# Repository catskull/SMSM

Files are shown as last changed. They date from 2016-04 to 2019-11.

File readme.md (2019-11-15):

# SMSM
## A MIDI interface for the Sega Master System

Originally developed by [little-scale](http://little-scale.blogspot.com/2012/12/how-to-build-sega-master-system-midi.html).

Updated and maintained by [catskull](http://catskull.net).

## Building the ROM
Install wla-dx. On OSX this is easily achieved using by using Homebrew. Simply call `brew install wla-dx` from a command line. If you get a linking error, run ```sudo chown -R `whoami`:admin /usr/local/bin` and then run `brew link wla-dx```. If that completed successfully, run `wla-z80` from the command line and you should see something like this:

```
WLA Z80 Macro Assembler v9.9
Written by Ville Helin in 1998-2008 - In GitHub since 2014: https://github.com/vhelin/wla-dx
$VER: WLA-Z80 9.9 (15.8.2019)

USAGE: wla-z80 [OPTIONS] <ASM FILE>

Options:
-i  Add list file information
-M  Output makefile rules
-q  Quiet
-t  Test compile
-v  Verbose messages
-x  Extra compile time labels & definitions
-I [DIR]  Include directory
-D [DEF]  Declare definition

Output types:
-o [FILE]  Output object file
-l [FILE]  Output library file

EXAMPLE: wla-z80 -v -o main.obj main.asm
```

Congratulations! You're now ready to build the ROM!

cd into the ROM directory. Inside there is SMSM.asm, and build.sh. Enter `./build.sh` from the command line and it will build the ROM for you! You should now see a file called output.sms in this directory. This is the rom! Fire up your favorite emulator and give it a shot!

## ROM improvements

The ROM as developed by little-scale works quite well but is very bare bones. For example, it does not display anything on the screen when booted so there's no way of knowing whether or not your cartridge even works or not!

Here is a list of improvements I've made to the ROM so far:
 - clear the bios screen on boot
 - display a message on boot "System ready!"

Wish list:
 - mGB style console based interface for editing instrument presets (currently that is only supported by MIDI CC commands)
 - Implement the reset button on the console to reset the rom (a sort of MIDI panic)
 - Display a message if the YM2413 FM sound chip is detected

# Hardware

The hardware as developed by little-scale is quite complete. It does most of the heavy lifting, which is why the console ROM is so bare bones.

Here is a list of improvements I have made:
 - Added a status LED on pin 13. It blinks in a pattern and then goes steady on on first boot. Once notes are being sent, it blinks each time a note is received.
 - Added a MIDI panic button. Pressing it will kill all notes on the console.
 - I have designed a small PCB based around the Arduino Pro Mini for easiest use.

Wish list:
 - Currently, the PCB does not work with a Game Gear. It simply does not power on. Powering the unit externally does not work either. It powers on, but will not receive any MIDI data.
 - The PCB interface does not work with my cheapie USB MIDI cable. It will occasionally get midi data, but not reliably and will frequently miss MIDI note off.

# Credits
Sebastian Tomczak (aka little-scale) for the ROM, arduino code, and everything else.

Maxim for a great hello world tutorial.

Everyone at smspower.org

# License

little-scale released this with this note:

"The code etc for this is open and free to use. Please do not commercialise this. It is not for making money. It is for making cool chiptune musics. I encourage you to build one of these. It is easy and shouldn't take long. I encourage you to hack the code and play and have fun with it."

This is not really a valid software license. The ROM is based on Maxim's hello world program which also was not really released with a license.

For the time being, the code is somewhere in between public domain and all rights reserved. All contributions I make will be licensed under GPL v2.

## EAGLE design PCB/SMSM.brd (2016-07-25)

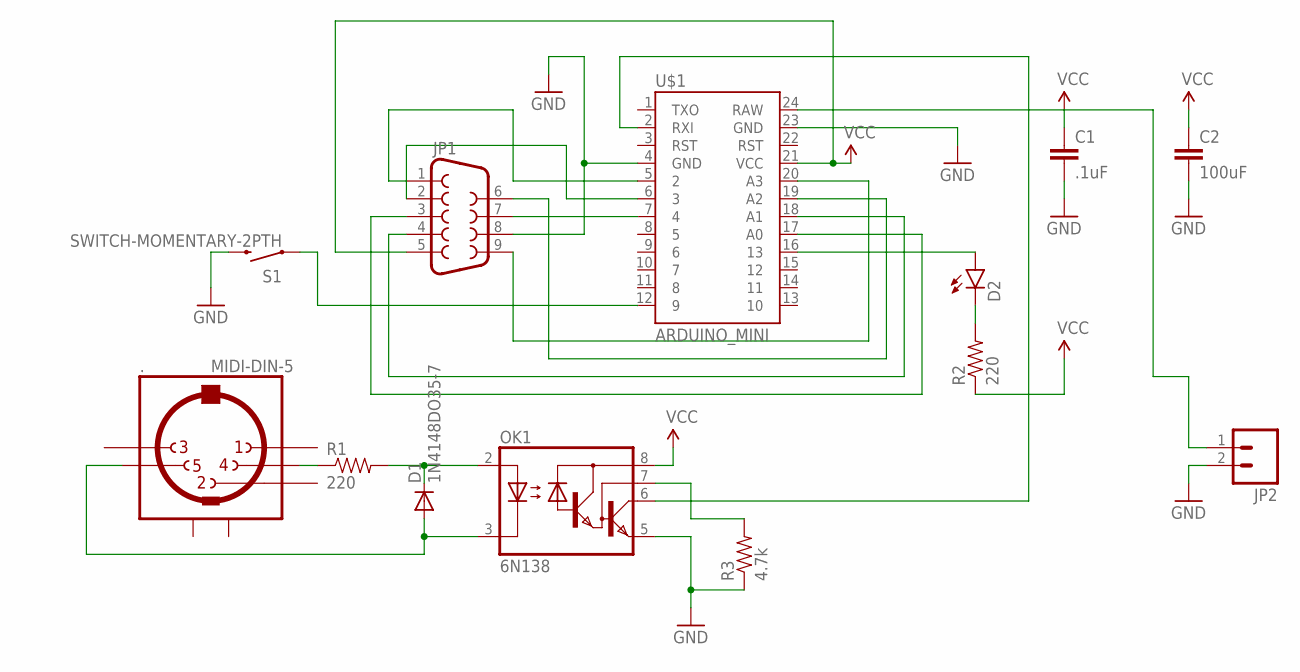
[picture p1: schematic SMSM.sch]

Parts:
.: MIDI-DIN-5
C1: .1uF; CAP-PTH-SMALL-KIT
C2: 100uF; CAP-PTH-SMALL-KIT
D1: 1N4148DO35-7; DO35-7
D2: LED3MM
JP1: DB9FEMALE; DB9
JP2: M02LOCK_LONGPADS; 1X02_LOCK_LONGPADS
OK1: 6N138; DIL08
R1, R2: 220; AXIAL-0.3
R3: 4.7k; AXIAL-0.3
S1: SWITCH-MOMENTARY-2PTH; TACTILE-PTH
U$1: ARDUINO_MINI

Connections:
GND: C1.2, C2.2, JP1.8, JP2.2, OK1.5 (GND), R3.P$1 (1), S1.3 (2), U$1.4 (GND), U$1.23 (GND)
unnamed: JP1.1, U$1.5 (2)
unnamed: JP1.2, U$1.6 (3)
unnamed: JP1.7, U$1.7 (4)
unnamed: D2.A, U$1.16 (13)
unnamed: JP1.3, U$1.17 (A0)
unnamed: JP1.4, U$1.18 (A1)
unnamed: JP1.6, U$1.19 (A2)
unnamed: JP1.9, U$1.20 (A3)
unnamed: ..5, D1.A, OK1.3 (C)
unnamed: D1.C, OK1.2 (A), R1.P$2 (2)
unnamed: D2.K (C), R2.P$2 (2)
unnamed: ..4, R1.P$1 (1)
unnamed: OK1.7 (VB), R3.P$2 (2)
unnamed: OK1.6 (VO), U$1.2 (RXI)
unnamed: S1.1, U$1.12 (9)
unnamed: JP2.1, U$1.24 (RAW)
VCC: C1.1, C2.1, JP1.5, OK1.8 (VCC), R2.P$1 (1), U$1.21 (VCC)

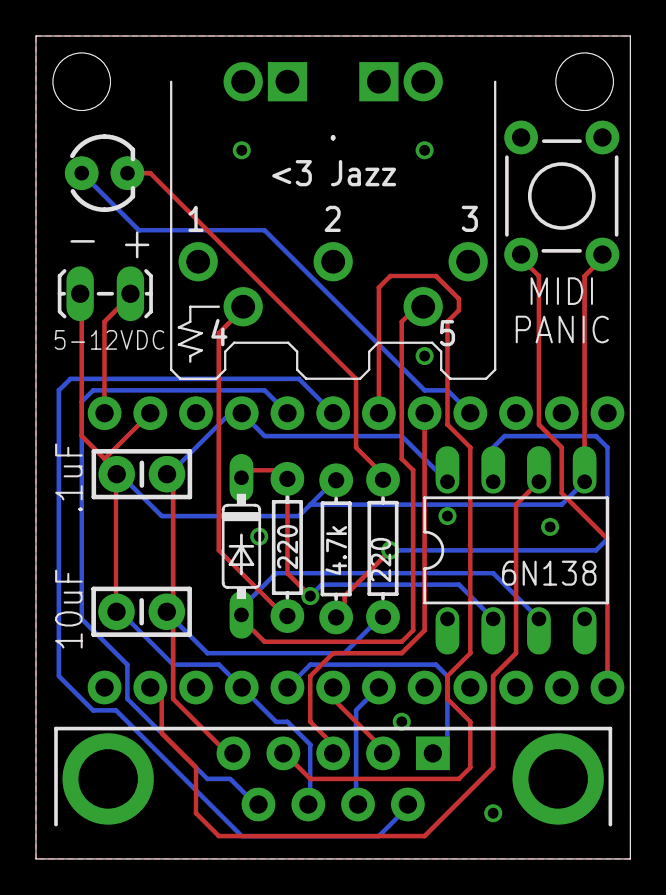
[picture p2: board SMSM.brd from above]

Board: 2 copper layers, 33.0 x 45.7 mm, 13 parts (0 on the bottom side), 18 nets.

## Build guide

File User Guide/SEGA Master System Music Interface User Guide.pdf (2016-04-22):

# SMSM INTERFACE USER GUIDE 1.00

SEGA Master System MIDI Interface User Guide by Sebastian Tomczak

## Contents

## Overview

The SMSM Interface allows one to have complete control over the two sound chips (The SN76489 and the YM2413 (optional in many systems)) within the SEGA Master System console via a MIDI connection.

The interface consists of two parts – a cartridge containing a custom program, and a hardware interface with pre-programmed microcontroller.

## Setup

1. Connect the SMSM hardware interface to the video game console via a 9-pin extension cable (available separately).
2. Connect the MIDI output from your host computer or other MIDI-enabled device to the SMSM hardware interface.
3. Insert the SMSM cartridge into the video game console.
4. Connect the audio output of the video game console to amplification or recording equipment. Video output is not needed. Depending on the console type, you may need to manually add audio outputs or use a DIN-type connection adaptor.
5. MIDI channels 1 to 4 are mapped to SN76489 channels 1 to 4.
6. MIDI channels 5 to 14 are mapped to YM2413 channels 1 to 9 (if YM2413 is available).

## SMSM MIDI Quick Reference

See the following sections for more information.

MIDI channels 1 to 4 are mapped to SN76489 channels 1 to 4.
MIDI channels 5 to 14 are mapped to YM2413 channels 1 to 9 (if YM2413 is available).

SN76489 PSG
Global Control
Parameter | CC | Data Range
Pitch Transposition | 42 | 128
PAL / NTSC Tuning | 83 | 2
Bass mode enabled | 85 | 2

Noise Channel Control (MIDI Ch 4)
C and C#: | High frequency, periodic type
D and D#: | Medium frequency, periodic type
E: | Low frequency, periodic type
F: | High frequency, noise type
F#: | Medium frequency, noise type
G and G#: | Low frequency, noise type
A and A#: | Frequency is determined by channel 3, periodic type
B: | Frequency is determined by channel 3, noise type

Voice Control
Parameter | CC | Data Range
AM mode enabled | 70 | 2
AM speed | 18 | 128
AM depth | 19 | 16
FM mode enabled | 71 | 2
FM speed | 20 | 128
FM depth | 21 | 128
Set channel volume | 11 | 16

Channel 2 Sample Mode

Parameter | CC | Data Range
Sample mode enabled | 78 | 2
Sample playback speed | 86 | 128

YM2413 FM
Global Control
Parameter | CC | Data Range
Set the value of A in Hz | 81 | 128
Equal Tempered Octave Division | 80 | 128
Set pitch bend resolution in semitones | 79 | 10.5
Percussion mode enabled | 78 | 2

Percussion Mode Control (MIDI Ch 14 when Percussion Mode is Enabled) C: Kick Drum
D: Snare Drum
E: Tom
F: Cymbal
G: Hi-hat

Voice Control
Parameter | CC | Data Range
Set instrument | 14 | 16
Custom voice AM (modulator) enabled | 15 | 2
Custom voice AM (carrier) enabled | 16 | 2
Custom voice Vib (m) enabled | 17 | 2
Custom voice Vib (c) enabled | 18 | 2
Custom voice EG type (m) | 19 | 2
Custom voice EG type (c) | 20 | 2
Custom voice KSR on (m) | 21 | 2
Custom voice KSR on (c) | 22 | 2
Custom voice mul (m) | 23 | 16
Custom voice mul (c) | 24 | 16
Custom voice KSL (m) | 25 | 4
Custom voice KSL (c) | 26 | 4

Custom voice TL modulation | 27 | 2
Custom voice rectify wave (m) | 28 | 2
Custom voice rectify wave (c) | 29 | 2
Custom voice FM feedback (m) | 30 | 16
Custom voice attack (m) | 31 | 16
Custom voice decay (m) | 32 | 16
Custom voice sustain (m) | 33 | 16
Custom voice release (m) | 34 | 16
Custom voice attack (c) | 35 | 16
Custom voice decay (c) | 36 | 16
Custom voice sustain (c) | 37 | 16
Custom voice release (c) | 38 | 16
Custom voice sustain mode enabled | 70 | 2

## MIDI Mapping – SN76489

The SN76489 PSG chip contains four channels that are mapped to MIDI channels 1 to 4. Channels 1, 2 and 3 are pulse channels that feature a simple tone generator, which can be used for melodic lines. Channel 4 is a pseudo-random noise generator, which can be used for percussion or effects. Channel 4 can be clocked using channel 3 (in other words – the pitch of channel 3 controls the pitch of channel 4).

The MIDI mapping for the SN76489 is relatively simple and straightforward compared with the YM2413. The SN76489 will respond to the following MIDI CC messages as well as note on, note off and pitch bend events.

SN76489: Global Parameters
PAL / NTSC Tuning | CC83 | Any Channel
2 values over the range of 0 to 127. A CC value of less than 64 sets the interface to the PAL tuning. A value of more than 63 sets the interface to the NTSC tuning. The default setting is PAL.
Pitch Transposition | CC42 | Any Channel
128 values of the range of 0 to 127. Set a global pitch offset of – 64 to + 63 semitones. Default is + or – 0 semitones which is equivalent to a CC value of 64.
Bass Mode Enabled | CC 85 | Any Channel
2 values over the range of 0 to 127. A CC of less than 64 disables Bass Mode for channel 2. A CC value of more than 63 enables Bass Mode for channel 2. When bass mode is enabled, the resources of SN76489 channels 3 and 4 are combined in such a way that MIDI channel 3 is a bass-like voice. This is a simple and musical way to 'clock' SN76489 channel 4 using SN76489 channel 3. See 'SN76489: Noise Channel Control' for more information.

SN76489: Noise Channel Control
The SN76489 has an interesting noise channel. The setting for the noise channel at a given point in time is selected by sending a note on event on MIDI channel 4. Any given pitch (regardless of octave) will produce a different setting for the noise channel, as follows:
C and C#: | High frequency, periodic type
D and D#: | Medium frequency, periodic type
E: | Low frequency, periodic type
F: | High frequency, noise type
F#: | Medium frequency, noise type

G and G#: | Low frequency, noise type
A and A#: | Frequency is determined by channel 9, periodic type
B: | Frequency is determined by channel 9, noise type

One way of handling the control of channel 4 using channel 3 is by sending note on events on channel 3 with a velocity below 7 (which will set the frequency of the noise channel) at the same time as sending note on events on channel 4 with a pitch of A, A# or B and with a high velocity (which will set the tone type – either noise or periodic – of the noise noise channel).

'Bass Mode' simplified way of controlling the frequency of the noise channel using channel 3. See 'Bass Mode Enabled' for more information.

SN76489: Voice Control Control
AM Mode Enabled | CC 70 | Channels 1, 2 and 3
2 values over the range of 0 to 127. A CC of less than 64 disables AM Mode a given channel. A CC value of more than 63 enables AM mode for a given channel. AM (amplitude modulation) allows for a range of effects, from timbral changes to tremolo and distortion.
AM Speed | CC18 | Channels 1, 2 and 3
128 values over the range of 0 to 127. The lower the CC value, the fast the speed of the amplitude modulation. Whether or not or not other MIDI channels are very active or have AM enabled will influence the actual frequency of the amplitude modulation for a given channel.
AM Depth | CC19 | Channels 1, 2 and 3
16 values over the range of 0 to 127. The lower the CC value, the less of an effect the amplitude modulation will have on a given voice.
FM (Vibrato) Mode Enabled | CC 70 | Channels 1, 2 and 3
2 values over the range of 0 to 127. A CC of less than 64 disables FM Mode a given channel. A CC value of more than 63 enables FM mode for a given channel. AM (frequency modulation) allows for a range of effects, from timbral changes to vibrato and distortion.
FM (Vibrato) Speed | CC18 | Channels 1, 2 and 3
128 values over the range of 0 to 127. The lower the CC value, the fast the speed of the amplitude modulation. Whether or not or not other MIDI channels are very active or have FM enabled will influence the actual frequency of the frequency modulation for a given channel.
FM (Vibrato) Depth | CC19 | Channels 1, 2 and 3

16 values over the range of 0 to 127. The lower the CC value, the less of an effect the frequency modulation will have on a given voice.
Set Channel Volume | CC11 | All Channels
16 values over the range of 0 to 127. Set the volume of a given channel. Can be used to draw envelopes.

SN76489: Channel 2 Sample Mode
Sample Mode Enabled | CC78 | Channel 2
2 values over the range of 0 to 127. A CC of less than 64 disables the sample mode. A CC value of more than 63 enables the sample mode. The sample mode can only be enabled for SN76489 channel 2. Note that due to the difference in volume for samples compared to the pulse waves, when sample mode is enabled, the volume of all notes is set to 1/3.
Sample Playback Speed | CC86 | Channel 2
128 values over the range of 0 to 127. The lower the CC value, the faster the sample playback speed is.

## MIDI Mapping – YM2413

The YM2413 is an FM chip and can play either 9 pitched channels or 6 pitches channels and 5 percussive sounds at once. The FM synthesis is relatively simple, and consists of a single modulator / single carrier-type model. The sound chip contains 15 preset instruments.

MIDI channels 5 to 13 are mapped to YM2413 pitched channels 1 to 9.
MIDI channel 14 is mapped to YM2413 percussion mode.

YM2413: Global Control
Set the value of A in Hz | CC81 | Any Channel
128 values over the range of 0 to 127. The value of the concert A and all other pitches relative to concert A is set by the following equation: Concert A = 381 + CC value (in Hz). For example, a CC value of 63 will give that Concert A = 381 + 63 = 440 Hz. This CC gives the user control over tuning; there is no need to change this CC from the default value in order to have standard tuning.
Equal Tempered Octave Division | CC80 | Any Channel
128 values over the range of 0 to 127. Sets the global equal-tempered division of the octave. The tuning of the interface is equal to (CC + 1) TET. The default is an equal division of the octave into twelve parts (the Western music scale), which is equivalent to a CC value of 11. Values above CC value = 17 may yield unexpected results. This CC gives the user control over tuning; there is no need to change this CC from the default value in order to have standard tuning.
Set Pitch Bend Resolution in Semitones | CC79 | Any Channel
10.5 values over the range of 0 to 127. Sets the global pitch-bend value in semitones, from +/- 0 semitones to +/- 12 semitones.
Percussion Mode Enabled | CC78 | Any Channel
2 values over the range of 0 to 127. A CC of less than 64 disables percussion mode. A CC value of more than 63 enables percussion mode. Percussion mode uses the resources of pitched channel 7, 8 and 9 in order to create 5 percussive sounds: kick drum, snare drum, tom, cymbal and hi-hat.

When in percussion mode:
- Only YM2413 pitched channels 1 to 6 are available for direct use
- As a result, only MIDI channels 5 to 10 will respond properly to MIDI note on / off events.
- MIDI channel 14 allows control over the YM2413 percussion mode

YM2413: Percussion Mode Control
MIDI Channel 14 control the percussive sounds. A note / off event for the following pitches (regardless of octave) will trigger the following percussive sounds when Percussion Mode is enabled (see 'Percussion Mode Enabled').

C: Kick Drum
D: Snare Drum
E: Tom
F: Cymbal
G: Hi-hat

Yamaha recommends a predetermined frequency setting for each of the operators that constitute the percussion when in drum mode, but these preset frequencies can sound quite bland and boring. By sending a CC value of more than 64, these preset-values are recalled automatically.

However, because these sounds are made using the operators that normally make up YM2413 pitched channels 7, 8 and 9, it is still possible to tune the operators to a certain degree by simply sending MIDI pitches to MIDI channels 11, 12 and 13. This then essentially 'tunes' the drum sounds, giving a wider variety of sounds, and even the possibility of playing melodies using the percussive sounds.

YM2413: Voice Control
Set Instrument | CC14 | Any Channel
16 values over the range of 0 to 127. Sets a given channel to an instrument preset. The instrument presets are as follows:
1. (Custom Voice)
2. Violin
3. Guitar
4. Piano
5. Flute
6. Clarinet
7. Oboe
8. Trumpet
9. Organ
10. Horn
11. Synthesizer
12. Harpsichord
13. Vibraphone

14. Synthesizer Bass
15. Acoustic Bass
16. Electric Bass

Note that the custom voice settings are identical for all channels – the custom voice is a global instrument with global parameters. See below for these parameters and how they are controlled.

Custom Voice AM (Modulator) Enabled | CC15 | Any Channel
2 values over the range of 0 to 127. A CC of less than 64 disables AM mode for the custom voice modulator. A CC value of more than 63 enables AM mode for the custom voice modulator.
Custom Voice AM (Carrier) Enabled | CC16 | Any Channel
2 values over the range of 0 to 127. A CC of less than 64 disables AM mode for the custom voice carrier. A CC value of more than 63 enables AM mode for the custom voice carrier.
Custom Voice Vibrato (Modulator) Enabled | CC17 | Any Channel
2 values over the range of 0 to 127. A CC of less than 64 disables vibrato mode for the custom voice carrier. A CC value of more than 63 enables vibrato mode for the custom voice carrier.
Custom Voice Vibrato (Carrier) Enabled | CC18 | Any Channel
2 values over the range of 0 to 127. A CC of less than 64 disables vibrato mode for the custom voice carrier. A CC value of more than 63 enables vibrato mode for the custom voice carrier.
Custom Voice EG Type (Modulator) | CC19 | Any Channel
2 values over the range of 0 to 127. A CC of less than 64 sets the envelope generator of the custom voice modulator to the sustained type. A CC of more than 63 sets the envelope generator of the custom voice modulator to the percussive type.
Custom Voice EG Type (Carrier) | CC20 | Any Channel
2 values over the range of 0 to 127. A CC of less than 64 sets the envelope generator of the custom voice carrier to the sustained type. A CC of more than 63 sets the envelope generator of the custom voice carrier to the percussive type.
Custom Voice KSR (Modulator) Enabled | CC21 | Any Channel
2 values over the range of 0 to 127. A CC of less than 64 disables key scale rate mode for the custom voice modulator. A CC value of more than 63 enables key scale rate mode for the custom voice modulator. Key scale rate can give instruments a more natural sound – as the pitch of the instrument rises, the amplitude envelope becomes faster.

Custom Voice KSR (Carrier) Enabled | CC22 | Any Channel
2 values over the range of 0 to 127. A CC of less than 64 disables key scale rate mode for the custom voice carrier. A CC value of more than 63 enables key scale rate mode for the custom voice carrier. Key scale rate can give instruments a more natural sound – as the pitch of the instrument rises, the amplitude envelope becomes faster.
Custom Voice Mul (Modulator) | CC23 | Any Channel
16 values over the range of 0 to 127. Sets the frequency multiplier of the custom voice modulator, from a ratio of ½ to a ratio of 15.
Custom Voice Mul (Carrier) | CC24 | Any Channel
16 values over the range of 0 to 127. Sets the frequency multiplier of the custom voice carrier, from a ratio of ½ to a ratio of 15.
Custom Voice KSL (Modulator) | CC25 | Any Channel
4 values over the range of 0 to 127. A CC of less than 64 disables key scale level mode for the custom voice modulator. A CC value of more than 63 enables key scale rate mode for the custom voice modulator. Key scale level can give instruments a more natural sound – as the pitch of the instrument rises, the output volume level drops.
Custom Voice KSL (Modulator) | CC26 | Any Channel
4 values over the range of 0 to 127. A CC of less than 64 disables key scale level mode for the custom voice carrier. A CC value of more than 63 enables key scale rate mode for the custom voice modulator. Key scale level can give instruments a more natural sound – as the pitch of the instrument rises, the output volume level drops.
Custom Voice TL Modulation | CC27 | Any Channel
64 values over the range of 0 to 127. The TL modulation controls the amount that the custom voice modulator modulates the custom voice carrier by. A wide variety of tones can be achieved by changing the TL modulation amount in conjunction with other custom voice parameters.
Custom Voice Rectify (Modulator) Enabled | CC28 | Any Channel
2 values over the range of 0 to 127. A CC of less than 64 disables rectify waveform mode for the custom voice modulator. A CC value of more than 63 enables rectify waveform mode for the custom voice modulator.
Custom Voice Rectify (Carrier) Enabled | CC29 | Any Channel
2 values over the range of 0 to 127. A CC of less than 64 disables rectify waveform mode for the custom voice modulator. A CC value of more than 63 enables rectify waveform mode for the custom voice modulator.

FM Feedback Amount | CC30 | Any Channel
8 values over the range of 0 to 127. Sets the amount of FM feedback. Distortion and timbre can be explored via this parameter.

One of the most important aspects of controlling the two operators of the YM2413 custom voice is through the amplitude (volume) envelope generator. Below is a basic representation of the envelope and its parameters. The YM2413 custom voice has one of two envelope types – either a sustained envelope or a percussive envelope. See 'Custom Voice EG Type (Modulator)'.

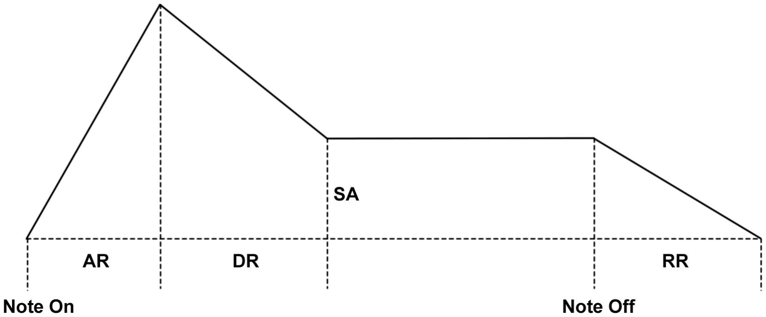
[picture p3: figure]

(envelope for a sustained envelope – see 'Custom Voice EG Type (Modulator)')

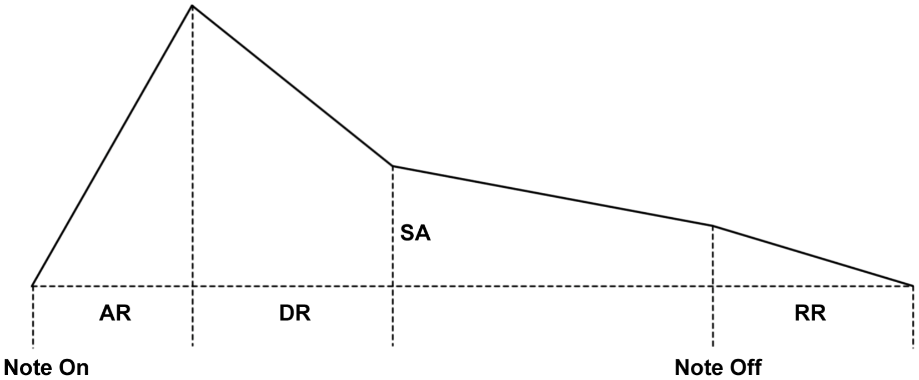
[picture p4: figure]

(envelope for a percussive envelope – see 'Custom Voice EG Type (Modulator)')

In relation to the above diagram, the horizontal axis represents time while the vertical axis represents amplitude. The Note On and Note Off events refer to their MIDI counter parts in the context of this MIDI interface.

AR = Attack Rate

DR = Decay Rate
SA = Sustain Amount
RR = Release Rate
Custom Voice Attack (Modulator) | CC31 | Any Channel
16 values over the range of 0 to 127. Sets the attack rate of the custom voice modulator.
Custom Voice Decay (Modulator) | CC32 | Any Channel
16 values over the range of 0 to 127. Sets the decay rate of the custom voice modulator.
Custom Voice Sustain (Modulator) | CC33 | Any Channel
16 values over the range of 0 to 127. Sets the attack rate of the custom voice modulator.
Custom Voice Release (Modulator) | CC34 | Any Channel
16 values over the range of 0 to 127. Sets the attack rate of the custom voice modulator.
Custom Voice Attack (Carrier) | CC35 | Any Channel
16 values over the range of 0 to 127. Sets the attack rate of the custom voice carrier.
Custom Voice Decay (Carrier) | CC36 | Any Channel
16 values over the range of 0 to 127. Sets the decay rate of the custom voice carrier.
Custom Voice Sustain (Carrier) | CC37 | Any Channel
16 values over the range of 0 to 127. Sets the attack rate of the custom voice carrier.
Custom Voice Release (Carrier) | CC38 | Any Channel
16 values over the range of 0 to 127. Sets the attack rate of the custom voice carrier.
Custom Voice Sustain Mode Enabled | CC70 | Any Channel
2 values over the range of 0 to 127. A CC of less than 64 disables sustain mode for the custom voice. A CC value of more than 63 enables sustain mode for the custom voice.

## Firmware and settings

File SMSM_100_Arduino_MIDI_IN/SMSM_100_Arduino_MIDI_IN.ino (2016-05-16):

// SEGA Master System MIDI Interface for Arduino MIDI In
// SMSM Firmware v1.0.1
// by little-scale
// Released 3 December 2012
// updated by catskull
// on 16 May 2016




/* Arduino Hardware

SMS Player 2 Port Pin 1 <-- Arduino Pin 2
SMS Player 2 Port Pin 2 <-- Arduino Pin 3
SMS Player 2 Port Pin 3 <-- Arduino Analog Input Pin 0
SMS Player 2 Port Pin 4 <-- Arduino Analog Input Pin 1
SMS Player 2 Port Pin 5 No Connection
SMS Player 2 Port Pin 6 <-- Arduino Analog Input Pin 2
SMS Player 2 Port Pin 7 <-- Arduino Pin 4
SMS Player 2 Port Pin 8 <-> Arduino Ground
SMS Player 2 Port Pin 9 <-- Arduino Analog Input Pin 3

*/




// Arduino Software


#include <avr/pgmspace.h>
#include <math.h>

#define MODE_NTSC 83
#define MODE_PAL 0

#define MIDI_PANIC_PRESSED 0
#define MIDI_PANIC_BUTTON 9

#define STATUS_LED 13

// FM VALUES

byte prev_address;
byte out_data;
byte shadow[56];
byte fm_pitches[9];

byte drum;
byte drum_key;
double fm_pitch;
int fm_bend_res = 12;
byte fm_pitch1;
byte fm_pitch2;
byte fm_block;
byte fm_offset;
int note_A = 444;
byte fm_octave_div = 12;
double fm_bend[9];





// SAMPLES BEGINS HERE
int SPB_flag = 0;
int SPB_sound = 0;
int SPB_counter = 0;
int SPB_speed = 0;
int SPB_tick = 1;
int sample_on = 0; // turn sample mode on
byte SPB_volume;

int SPB_max = 400;

int sample_length_list[] = {
  900, // kick 1
  600, // snare 1
  400, // hat c1
  900, // hat o1
  1300, // tom1
  4000, // ride1
  400,
  300,
  1000,
  2000,
  2000,
  1500,
  720,
  1500,
  1500,
  900,
  500,
  1500,
  1000,
  1000
};






const char kick1[] PROGMEM = {
119, 120, 135, 118, 102, 84, 67, 50, 16, 17, 33, 38, 120, 171, 188, 240, 255, 255, 255, 255, 255, 255, 238, 237, 203, 187, 170, 153, 137, 136, 119, 119, 118, 101, 84, 67, 50, 33, 17, 17, 17, 17, 17, 34, 34, 34, 35, 51, 51, 51, 68, 68, 85, 85, 102, 103, 119, 119, 136, 135, 120, 136, 136, 136, 153, 153, 154, 170, 187, 187, 187, 188, 203, 187, 187, 187, 187, 187, 170, 170, 170, 170, 170, 170, 170, 170, 170, 170, 170, 153, 153, 136, 136, 135, 119, 119, 102, 102, 102, 102, 102, 85, 85, 85, 85, 85, 85, 85, 85, 86, 102, 102, 101, 85, 85, 85, 86, 102, 102, 103, 119, 119, 136, 136, 136, 137, 153, 153, 153, 153, 153, 153, 153, 153, 153, 154, 170, 170, 170, 170, 153, 153, 153, 152, 136, 136, 136, 135, 119, 119, 119, 119, 120, 136, 136, 136, 135, 119, 119, 119, 119, 119, 119, 119, 119, 119, 119, 119, 119, 119, 119, 119, 119, 119, 119, 119, 118, 102, 119, 119, 119, 119, 119, 119, 119, 119, 119, 119, 119, 119, 136, 136, 136, 136, 136, 136, 136, 136, 136, 136, 136, 136, 136, 136, 136, 136, 136, 136, 136, 136, 136, 136, 136, 136, 136, 136, 136, 136, 136, 136, 136, 136, 136, 136, 136, 136, 136, 136, 136, 136, 136, 136, 136, 136, 136, 136, 119, 119, 119, 119, 119, 119, 119, 119, 119, 119, 119, 119, 119, 119, 119, 119, 119, 119, 119, 119, 119, 119, 119, 119, 119, 136, 136, 136, 136, 136, 136, 136, 136, 119, 119, 119, 119, 119, 119, 119, 119, 119, 119, 136, 136, 136, 136, 136, 136, 136, 136, 136, 136, 136, 136, 136, 136, 136, 136, 136, 136, 136, 136, 136, 136, 136, 136, 135, 119, 119, 119, 119, 119, 119, 119, 119, 119, 119, 119, 119, 119, 119, 119, 119, 119, 119, 119, 119, 119, 119, 119, 119, 119, 119, 119, 119, 119, 119, 119, 119, 119, 119, 119, 119, 119, 119, 119, 119, 119, 119, 119, 119, 136, 136, 136, 136, 136, 136, 136, 136, 136, 136, 136, 136, 136, 136, 136, 136, 136, 136, 136, 136, 136, 136, 136, 136, 136, 136, 135, 119, 119, 119, 119, 119, 119, 119, 119, 119, 119, 136, 136, 136, 136, 136, 136, 136, 136, 119, 119, 119, 119, 119, 119, 119, 119, 119, 119, 119, 119, 119, 119, 119, 119, 119, 119, 119, 119, 119, 119, 119, 119, 119, 119, 136, 136, 136, 136, 136, 136, 136, 136, 136, 136, 136, 136, 136, 136, 136, 136, 136, 136, 136, 136, 136, 136, 136, 136, 136, 136, 136, 136, 136, 136, 136
};

const char snare1[] PROGMEM = {
136, 119, 119, 123, 256, 255, 155, 0, 1, 57, 206, 239, 255, 222, 219, 135, 32, 0, 0, 0, 19, 189, 191, 255, 255, 238, 182, 0, 0, 0, 3, 57, 207, 236, 255, 254, 220, 16, 0, 4, 52, 101, 136, 137, 204, 205, 254, 154, 115, 18, 18, 20, 84, 185, 189, 204, 202, 155, 153, 103, 84, 101, 70, 117, 103, 168, 138, 136, 153, 169, 170, 134, 104, 117, 86, 119, 100, 104, 137, 152, 171, 185, 152, 153, 117, 103, 70, 120, 103, 103, 118, 154, 139, 186, 135, 153, 118, 87, 82, 69, 104, 137, 170, 136, 153, 137, 134, 102, 118, 103, 85, 120, 102, 120, 122, 136, 137, 136, 152, 134, 102, 102, 103, 118, 119, 104, 136, 136, 136, 120, 152, 120, 119, 103, 104, 119, 136, 134, 151, 134, 136, 137, 136, 136, 134, 119, 100, 102, 102, 120, 137, 152, 153, 152, 136, 136, 117, 118, 118, 119, 120, 120, 120, 152, 152, 136, 118, 119, 119, 136, 119, 135, 103, 120, 135, 119, 136, 136, 135, 135, 118, 120, 119, 136, 136, 120, 136, 120, 120, 118, 136, 119, 120, 120, 118, 119, 120, 136, 120, 136, 136, 119, 136, 119, 119, 119, 119, 136, 136, 120, 136, 136, 120, 135, 103, 119, 119, 118, 136, 135, 152, 136, 136, 119, 135, 119, 119, 119, 135, 120, 136, 135, 135, 119, 135, 119, 135, 136, 135, 120, 135, 136, 135, 119, 119, 120, 136, 135, 120, 136, 120, 135, 119, 119, 120, 119, 119, 120, 120, 136, 119, 119, 119, 119, 119, 119, 135, 136, 136, 135, 119, 119, 135, 119, 135, 135, 120, 136, 120, 136, 135, 135, 135, 119, 119, 119, 119, 119, 120, 120, 136, 136, 136, 119, 119, 119, 135, 119, 119, 120
};

const char hatc1[] PROGMEM = {
136, 136, 133, 112, 58, 34, 104, 75, 119, 25, 114, 72, 103, 54, 184, 150, 86, 102, 135, 149, 73, 185, 101, 134, 69, 104, 118, 136, 134, 185, 119, 104, 151, 104, 197, 214, 121, 119, 134, 134, 121, 152, 118, 118, 135, 169, 119, 135, 120, 136, 105, 136, 152, 151, 104, 104, 134, 120, 137, 103, 103, 103, 118, 120, 120, 136, 137, 120, 120, 104, 135, 119, 151, 136, 151, 136, 119, 119, 120, 120, 136, 136, 120, 136, 119, 136, 136, 135, 136, 120, 120, 135, 135, 135, 135, 120, 135, 120, 136, 135, 135, 120, 135, 136, 135, 135, 119, 136, 136, 120, 120, 135, 119, 119, 120, 120, 136, 120, 119, 135, 119, 119, 135, 135, 119, 135, 136, 119, 119, 135, 119, 135, 135, 120, 119, 135, 120, 120, 119, 136, 119, 119, 120, 119, 135, 135, 120, 119, 119, 119, 119, 135, 119, 119, 119, 119, 120, 119, 119, 119, 135, 136, 119, 119, 119, 119, 119, 119, 119, 119, 119, 135, 119, 119, 135, 120, 119, 135, 120, 135, 119, 119, 119, 119, 136, 135, 119, 136, 120, 119, 136, 120, 135, 135, 120, 119, 135, 136, 119, 119
};

const char hato1[] PROGMEM = {
120, 136, 136, 117, 111, 169, 85, 90, 119, 199, 167, 166, 55, 74, 53, 123, 105, 92, 73, 182, 80, 166, 107, 135, 86, 140, 135, 103, 119, 171, 118, 138, 165, 106, 152, 89, 136, 117, 237, 120, 119, 136, 153, 101, 134, 204, 187, 116, 135, 137, 214, 102, 70, 118, 153, 136, 102, 116, 153, 119, 87, 133, 137, 118, 91, 104, 155, 149, 105, 139, 152, 86, 104, 120, 169, 166, 26, 121, 138, 101, 134, 184, 120, 182, 139, 108, 104, 119, 101, 118, 136, 105, 120, 138, 119, 133, 168, 104, 153, 103, 86, 170, 135, 135, 119, 120, 120, 119, 119, 103, 117, 136, 105, 120, 87, 135, 135, 137, 151, 118, 105, 136, 119, 119, 134, 120, 185, 152, 135, 136, 138, 136, 136, 151, 135, 136, 151, 152, 136, 105, 87, 118, 152, 103, 147, 165, 119, 118, 152, 121, 168, 136, 135, 120, 118, 87, 105, 25, 120, 152, 119, 151, 150, 154, 70, 86, 120, 120, 102, 134, 103, 119, 121, 119, 120, 119, 135, 135, 119, 120, 136, 135, 152, 120, 169, 170, 152, 134, 136, 121, 119, 151, 135, 152, 120, 135, 121, 87, 135, 167, 136, 134, 136, 103, 122, 134, 136, 135, 120, 153, 152, 120, 120, 120, 119, 119, 183, 137, 136, 121, 135, 152, 151, 103, 135, 120, 135, 120, 135, 119, 119, 135, 119, 136, 136, 119, 119, 120, 135, 136, 120, 118, 120, 150, 152, 119, 120, 153, 121, 119, 119, 120, 135, 167, 87, 135, 136, 136, 86, 104, 135, 152, 120, 120, 136, 152, 119, 136, 135, 120, 121, 118, 104, 137, 135, 119, 120, 118, 119, 119, 136, 151, 120, 135, 152, 135, 120, 120, 120, 136, 135, 135, 136, 136, 135, 118, 136, 120, 136, 119, 120, 135, 121, 135, 119, 119, 136, 120, 119, 135, 103, 120, 120, 119, 135, 120, 135, 119, 119, 120, 119, 134, 135, 135, 119, 119, 119, 120, 104, 119, 135, 136, 119, 136, 151, 104, 120, 120, 136, 136, 119, 119, 120, 136, 136, 135, 119, 135, 119, 135, 136, 119, 119, 135, 120, 120, 136, 135, 135, 119, 136, 119, 135, 119, 136, 119, 119, 119, 119, 119, 119, 135, 119, 135, 134, 120, 119, 120, 119, 119, 136, 134, 136, 120, 119, 136, 134, 135, 119, 120, 136, 135, 135, 120, 135, 136, 119, 136, 135, 120, 120, 135, 135, 136, 135, 120, 135, 135, 136, 135, 136, 119, 120, 136, 136, 135, 119, 119, 136, 135, 119, 119, 120, 120, 135, 120, 119, 136, 119, 119, 119, 120, 135, 120, 119, 119, 136, 120, 119, 119, 120, 119, 119, 136, 135, 120, 119, 119, 136, 120
};

const char tom1[] PROGMEM = {
136, 136, 136, 137, 154, 223, 200, 109, 0, 36, 49, 5, 108, 240, 253, 235, 134, 116, 83, 35, 99, 32, 3, 57, 171, 137, 254, 255, 253, 151, 132, 118, 68, 17, 20, 102, 136, 137, 174, 255, 254, 185, 137, 135, 132, 33, 34, 85, 87, 104, 137, 187, 205, 222, 221, 185, 150, 85, 50, 35, 52, 70, 102, 136, 155, 220, 204, 188, 186, 136, 134, 101, 68, 66, 36, 84, 103, 136, 154, 187, 204, 204, 185, 152, 118, 86, 85, 84, 84, 68, 86, 103, 137, 170, 189, 220, 187, 170, 152, 118, 84, 68, 68, 68, 84, 86, 103, 137, 187, 204, 220, 186, 169, 152, 118, 85, 50, 51, 69, 85, 102, 120, 154, 171, 204, 187, 187, 169, 135, 101, 68, 67, 68, 68, 86, 119, 120, 138, 171, 188, 203, 186, 168, 135, 102, 85, 68, 68, 68, 86, 103, 136, 154, 187, 187, 170, 170, 152, 136, 118, 102, 85, 68, 68, 86, 103, 136, 137, 170, 170, 170, 170, 153, 136, 118, 101, 85, 85, 86, 102, 119, 119, 120, 153, 153, 169, 153, 154, 152, 136, 118, 102, 102, 102, 102, 102, 103, 119, 120, 136, 136, 137, 153, 153, 153, 153, 152, 135, 102, 101, 85, 86, 102, 103, 119, 120, 153, 154, 170, 170, 169, 153, 136, 119, 118, 85, 85, 69, 86, 102, 120, 137, 170, 170, 169, 153, 153, 152, 136, 119, 118, 101, 85, 85, 86, 119, 120, 137, 153, 153, 153, 153, 153, 152, 136, 119, 119, 102, 102, 101, 102, 102, 103, 119, 137, 153, 154, 169, 153, 153, 136, 135, 118, 102, 102, 102, 102, 101, 103, 120, 136, 153, 153, 153, 153, 152, 136, 136, 135, 119, 119, 118, 102, 102, 102, 103, 120, 136, 136, 136, 137, 153, 153, 153, 136, 136, 136, 119, 118, 101, 101, 85, 102, 103, 120, 153, 170, 169, 153, 136, 136, 136, 136, 136, 119, 102, 85, 85, 86, 103, 120, 152, 153, 153, 153, 153, 136, 136, 136, 136, 119, 119, 118, 102, 102, 102, 103, 119, 136, 153, 153, 153, 153, 152, 136, 136, 136, 135, 119, 119, 119, 102, 102, 102, 119, 120, 136, 137, 153, 153, 152, 136, 136, 136, 136, 119, 119, 102, 102, 102, 102, 103, 120, 137, 153, 153, 153, 153, 136, 136, 136, 136, 135, 119, 102, 102, 102, 102, 103, 120, 136, 153, 137, 136, 153, 152, 136, 136, 135, 119, 119, 119, 119, 102, 102, 119, 119, 120, 136, 153, 153, 153, 152, 136, 136, 135, 136, 136, 119, 119, 119, 102, 102, 119, 119, 119, 136, 153, 153, 153, 136, 136, 136, 136, 135, 120, 119, 119, 119, 103, 102, 102, 119, 120, 136, 137, 153, 153, 153, 136, 136, 119, 119, 119, 119, 119, 119, 102, 102, 119, 119, 136, 153, 153, 153, 153, 152, 136, 119, 119, 119, 119, 119, 119, 119, 119, 119, 119, 119, 136, 136, 136, 136, 136, 136, 136, 136, 136, 136, 135, 119, 119, 119, 119, 119, 119, 119, 119, 136, 136, 136, 136, 153, 136, 136, 136, 136, 135, 119, 119, 102, 102, 119, 119, 119, 136, 136, 136, 136, 136, 136, 136, 136, 119, 119, 119, 119, 119, 119, 119, 119, 119, 119, 119, 136, 136, 136, 136, 136, 136, 136, 136, 136, 119, 119, 119, 119, 119, 119, 119, 118, 119, 119, 136, 136, 153, 153, 152, 136, 136, 136, 119, 119, 119, 119, 119, 119, 119, 119, 119, 119, 136, 136, 137, 153, 153, 136, 136, 136, 135, 119, 119, 119, 119, 119, 119, 119, 119, 120, 136, 136, 136, 136, 136, 136, 136, 136, 136, 119, 119, 119, 119, 119, 119, 119, 119, 119, 136, 136, 136, 136, 136, 136, 136, 136, 136, 135, 119, 119, 119, 119, 119, 119, 119, 119, 136, 136, 136, 136, 136, 136, 136, 136, 135, 119, 119, 119, 119, 119, 119
};
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
void loop() {
  doMidiPanic();
  doAM();
  doVib();
  doSample();

// Dealing with initial serial data

  if(Serial.available() > 0) {
    dataIn = Serial.read();
    if(dataIn < 0x80 && flag_previous == 0) {
      doMidiIn(rstat);
    }
    doMidiIn(dataIn);
  }
}


void doMidiPanic() {
  if(digitalRead(MIDI_PANIC_BUTTON) == MIDI_PANIC_PRESSED) {
    for(byte i = 0; i < 14; i++) {
      doNoteOff(i, 0, 0);
    }
  }
}


// Dealing with MIDI data

void doNoteOn(byte channel, byte pitch, byte velocity) {
  // Turn on the status LED
  digitalWrite(STATUS_LED, LOW);

// YM2413 NOTE ON EVENTS

  if((channel == 13) && ((shadow[0x0e] & B00100000) == 0x20)) {
   doDrums(pitch % 12, velocity);
  }

  else if(channel >= 4 && channel <= 12) {
    channel = channel - 4;

    if(velocity > 0) {

    // write the pitch and volume
    fm_pitch = pitch + fm_offset;
    fm_pitches[channel] = fm_pitch;
    fm_block = (byte(fm_pitch + fm_bend[channel]) / byte(fm_octave_div)) % 8;

    fm_pitch = ((note_A * pow(2, ((fm_pitch - 69 + fm_bend[channel]) / fm_octave_div) )) * (pow(2, 18) / 50000)) / pow(2, fm_block - 1);
    fm_pitch1 = int(fm_pitch) % 256;
    fm_pitch2 = int(fm_pitch) / 256;

    shadow[0x20 + channel] = (shadow[0x20 + channel] & B11100000) | ((fm_block << 1) + fm_pitch2 + B00010000);
    shadow[0x30 + channel] = (shadow[0x30 + channel] & B11110000) | (15 - (velocity >> 3));

    writeYM2413(0x10 + channel, fm_pitch1);
    writeYM2413(0x20 + channel, shadow[0x20 + channel]);
    writeYM2413(0x30 + channel, shadow[0x30 + channel]);
    }

    else {
      shadow[0x30 + channel] = (shadow[0x30 + channel] & B11110000) | B00001111;
      shadow[0x20 + channel] = shadow[0x20 + channel] & B11101111;
      writeYM2413(0x30 + channel, shadow[0x30 + channel]);
      writeYM2413(0x20 + channel, shadow[0x20 + channel]);
    }
  }



  // SN76489 SAMPLE PLAYBACK ON CHANNEL 2
  else if(channel == 1 && sample_on == 1) {
    SPB_sound = pitch % 24;
    if(velocity > 0) {
      SPB_flag = 1;
      SPB_counter = 0;
      SPB_max = sample_length_list[SPB_sound];
    }

    else {
      SPB_flag = 0;
    }
  }



  // SN76489 BASS MODE
  else if(channel == 2 && bass_mode == 1) {
    if(sample_on == 1)
    {
      velocity = velocity / 3;
    }


    writeSN76489(B11100011); // clock by frequency
    if(velocity > 0) {
      int coarsePitchVal = -12 + (coarsePitch[channel] / 5);
      pitchData[channel] = pitch;
      velocityData[channel + 1] = velocity;
      writeFrequency(pitch, channel);
      writeAmplitude(velocity, channel + 1);
    }

    else {
      velocityData[channel + 1] = 0;
      writeAmplitude(0, channel + 1);
    }
  }




  // NORMAL PULSE CHANNELS
  else if(channel >= 0 && channel <= 2 && pitch >= 45) {

    if(sample_on == 1)
    {
      velocity = velocity / 3;
    }

    if(velocity > 0) {
      int coarsePitchVal = -12 + (coarsePitch[channel] / 5);
      pitchData[channel] = pitch;
      velocityData[channel] = velocity;
      writeFrequency(pitch, channel);
      writeAmplitude(velocity, channel);
    }

    else {
      velocityData[channel] = 0;
      writeAmplitude(0, channel);
    }
  }

  // NOISE
  else if(channel == 3) {
        if(sample_on == 1)
    {
      velocity = velocity / 3;
    }

    if(velocity > 0) {
      velocityData[channel] = velocity;
      writeSN76489(noiseLookup[pitch % 12]);
      writeAmplitude(velocity, channel);
    }

    else {
      velocityData[channel] = 0;
      writeAmplitude(0, channel);
    }
  }
}


void doNoteOff(byte channel, byte pitch, byte velocity) {
    // Turn off the status LED
    digitalWrite(STATUS_LED, HIGH);

    if((channel == 13) && ((shadow[0x0e] & B00100000) == 0x20)) {
       doDrums(pitch % 12, 0);
    }

    else if(channel >= 4 && channel <= 12) {
      channel = channel - 4;
      shadow[0x30 + channel] = (shadow[0x30 + channel] & B11110000) | B00001111;
      shadow[0x20 + channel] = shadow[0x20 + channel] & B11101111;
      writeYM2413(0x30 + channel, shadow[0x30 + channel]);
      writeYM2413(0x20 + channel, shadow[0x20 + channel]);
  }

  else if(channel == 1 && sample_on == 1) {
    SPB_flag = 0;
  }

  else if(channel == 2 && bass_mode == 1) {
    writeAmplitude(0, channel + 1);
  }

  else {
    velocityData[channel] = 0;
    writeAmplitude(0, channel);
  }
}



void doCC(byte channel, byte ccnumber, byte ccvalue) {
  // SN76489 MIDI CC
  if(channel >=0 && channel <=3) {
  // CC83 = tuning mode
  if(ccnumber == 83 && channel == 0) {
    if(ccvalue > 63) {
      pitchTableOffset = 83;
    }
    else{
      pitchTableOffset = 0;
    }
  }

  // MIDI CC 42 = coarse tuning
  else if(ccnumber == 42 && channel >= 0 && channel <= 3) {
    coarsePitch[channel] = ccvalue;
    writeFrequency(pitchData[channel], channel);
  }



  // MIDI CC 70 = AM On
  else if(ccnumber == 70 && channel >= 0 && channel <= 3) {
    amModOn[channel] = ccvalue >> 6;
  }

  // MIDI CC 18 = AM Speed
  else if(ccnumber == 18 && channel >= 0 && channel <= 3) {
    amSpeed[channel] = ccvalue;
  }

  // MIDI CC 19 = AM Depth
  else if(ccnumber == 19 && channel >= 0 && channel <= 3) {
    amDepth[channel] = ccvalue;
  }

  // MIDI CC 71 = Vib On
  else if(ccnumber == 71 && channel >= 0 && channel <= 2) {
    vibModOn[channel] = ccvalue >> 6;
  }

  // MIDI CC 20 = Vib Speed
  else if(ccnumber == 20 && channel >= 0 && channel <= 2) {
    vibSpeed[channel] = ccvalue;
  }

  // MIDI CC 21 = Vib Depth
  else if(ccnumber == 21 && channel >= 0 && channel <= 2) {
    vibDepth[channel] = ccvalue;
  }

  // MIDI CC 11 = expression
  else if(ccnumber == 11 && channel >= 0 && channel <= 3) {
    velocityData[channel] = ccvalue;
    writeAmplitude(ccvalue, channel);
  }

  // MIDI CC 78 = sample mode on
  else if(ccnumber == 78) {
    if(ccvalue > 63) {
      writeSN76489(B10100000);
      writeSN76489(B00000000);
    }
    sample_on = ccvalue >> 6;

  }

    // MIDI CC 86 = sample playback speed
  else if(ccnumber == 86) {
    SPB_speed = ccvalue;
  }

      // MIDI CC 85 = bass mode
  else if(ccnumber == 85) {
    bass_mode = ccvalue >> 6;
  }

  }
   // YM2413 MIDI CC
    else if(channel >=4 && channel <=14) {
      channel = channel - 4;

      switch(ccnumber) {
        case 14: // set instrument
        shadow[0x30 + channel] = (shadow[0x30 + channel] & B00001111) | ((ccvalue >> 3) << 4);
        writeYM2413(0x30 + channel, shadow[0x30 + channel]);
        break;

        // register $00 - $01

        case 15: // AM on (mod)
        shadow[0x00] = (shadow[0x00] & B01111111) | ((ccvalue >> 6) << 7);
        writeYM2413(0x00, shadow[0x00]);
        break;

        case 16: // AM on (carrier)
        shadow[0x01] = (shadow[0x01] & B01111111) | ((ccvalue >> 6) << 7);
        writeYM2413(0x01, shadow[0x01]);
        break;

        case 17: // vib on (m)
        shadow[0x00] = (shadow[0x00] & B10111111) | ((ccvalue >> 6) << 6);
        writeYM2413(0x00, shadow[0x00]);
        break;

        case 18: // vib on (c)
        shadow[0x01] = (shadow[0x01] & B10111111) | ((ccvalue >> 6) << 6);
        writeYM2413(0x01, shadow[0x01]);
        break;

        case 19: // EG type (m)
        shadow[0x00] = (shadow[0x00] & B11011111) | ((ccvalue >> 6) << 5);
        writeYM2413(0x00, shadow[0x00]);
        break;

        case 20: // EG type (c)
        shadow[0x01] = (shadow[0x01] & B11011111) | ((ccvalue >> 6) << 5);
        writeYM2413(0x01, shadow[0x01]);
        break;

        case 21: // KSR on (m)
        shadow[0x00] = (shadow[0x00] & B11101111) | ((ccvalue >> 6) << 4);
        writeYM2413(0x00, shadow[0x00]);
        break;

        case 22: // KSR on (c)
        shadow[0x01] = (shadow[0x01] & B11101111) | ((ccvalue >> 6) << 4);
        writeYM2413(0x01, shadow[0x01]);
        break;

        case 23: // mul (m)
        shadow[0x00] = (shadow[0x00] & B11110000) | (ccvalue >> 3);
        writeYM2413(0x00, shadow[0x00]);
        break;

        case 24: // mul (c)
        shadow[0x01] = (shadow[0x01] & B11110000) | (ccvalue >> 3);
        writeYM2413(0x01, shadow[0x01]);
        break;

        // register $02 - $03

        case 25: // ksl (m)
        shadow[0x02] = (shadow[0x02] & B00111111) | ((ccvalue >> 5) << 6);
        writeYM2413(0x02, shadow[0x02]);
        break;

        case 26: // ksl (c)
        shadow[0x03] = (shadow[0x03] & B00111111) | ((ccvalue >> 5) << 6);
        writeYM2413(0x03, shadow[0x03]);
        break;

        case 27: // TL modulation
        shadow[0x02] = (shadow[0x02] & B11000000) | (ccvalue >> 1);
        writeYM2413(0x02, shadow[0x02]);
        break;

        case 28: // rect (m)
        shadow[0x03] = (shadow[0x03] & B11110111) | ((ccvalue >> 6) << 3);
        writeYM2413(0x03, shadow[0x03]);
        break;
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

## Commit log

2016-05-16 Add midi panic button
2016-05-16 Add status led stuff
2016-07-25 Add boards
    [SMSM.brd, SMSM.sch]

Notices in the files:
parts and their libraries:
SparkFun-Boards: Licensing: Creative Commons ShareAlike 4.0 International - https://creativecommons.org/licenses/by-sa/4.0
